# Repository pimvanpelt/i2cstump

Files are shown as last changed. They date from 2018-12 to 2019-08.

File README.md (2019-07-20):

# Digistump I2C dongle

## Version 4 - USB Dongle

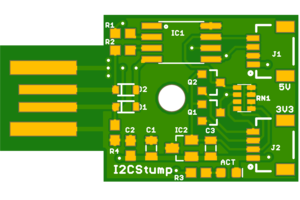
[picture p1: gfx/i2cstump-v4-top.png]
Top of I2CStump

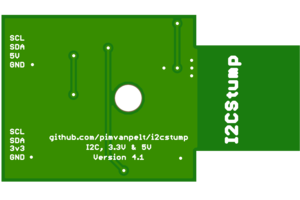
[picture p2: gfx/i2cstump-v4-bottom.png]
Bottom of I2CStump


## Version 5 - USB-C Connector

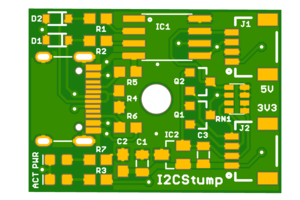
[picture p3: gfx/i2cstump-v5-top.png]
Top of I2CStump

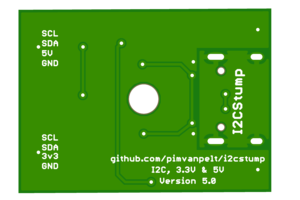
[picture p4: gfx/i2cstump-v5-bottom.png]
Bottom of I2CStump


## Hardware 

This device is an adaptation of [Digistump](http://digistump.com/products/1)'s
USB device, with two added [Qwiic](https://www.sparkfun.com/qwiic) connectors.
The first is used as a 5V I2C port, and the second has a level shifter to 3.3V
using [BSS138](https://www.onsemi.com/pub/Collateral/BSS138-D.PDF) FETs to
create a 3.3V I2C port. It's slightly bigger than the original, coming in 
at 34.0 x 18.7 mm (for the stump, which plugs directly into a USB port), or
25.9 x 18.8 mm (for the USB-C version)..

See my Oshpark projects: [v2](https://oshpark.com/shared_projects/iBBtdp7S),
[v3](https://oshpark.com/shared_projects/8I7qjXw7), 
[v4](https://oshpark.com/shared_projects/ChwKt4Mn),
[current-v5](https://oshpark.com/shared_projects/Jq9YXZ0q).

You can see a few pictures of the v3 board [here](https://photos.app.goo.gl/4XRo74y9Bt4kZoqR7).

### Bill of Materials

*   C1,C3: Tantalum 4.7 μF (0805)
*   C2: Ceramic 0.1 μF (0603)
*   D1,D2: 3.6V Zener (SOD-323)
*   D3: Blue (activity) LED (0603)
*   D4: Red (power) LED (0603)
*   IC1: ATTINY85 (SO08)
*   IC2:
    *   v2: AM1117 3.3V (SOT223)
    *   v3+: MCP1703 3.3V (SOT23)
*   J1,J2: QWIIC Connector (1X04 1MM RA)
*   Q1,Q2: BSS138 (SOT23-3)
*   R1,R2: 66 Ω (0603)
*   R3,R7: 680 Ω (0603)
*   R4: 2.2 kΩ (0603)
*   R5,R6: 5.1 kΩ (0603)
*   RN1: 10 kΩ (0805)
*   USB-C 16 pin connector

To build this board by hand, take a look at the [instructions](BUILDING.md).

## Firmware

The ATTiny85 is first flashed with [Micronucleus](https://github.com/micronucleus/micronucleus),
a bootloader which equips the microcontroller with a minimal USB interface. You can use the
`ICSP` touchpoint header at the bottom of the board to flash.

Firmware which runs under the micronucleus bootloader is [I2C-Tiny-USB](https://github.com/harbaum/I2C-Tiny-USB)
which is detected under Linux using the [i2c-tiny-usb](https://github.com/torvalds/linux/blob/master/drivers/i2c/busses/i2c-tiny-usb.c)
driver.

## Acknowledgements

Thanks go to:

*   Digistump LLC for sharing the original for this device under Creative Commons.
*   Tim Böscke, Jenna Fox, Shay Green et al for the Micronucleus bootloader.
*   Till Harbaum for an excellent ATTINY85 firmware for an I2C bridge.

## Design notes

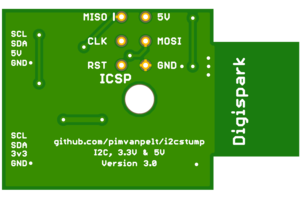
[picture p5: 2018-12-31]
gfx/i2cstump-v3-bottom.png

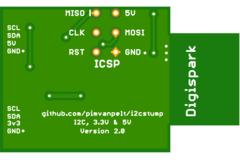
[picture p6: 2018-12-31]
gfx/i2cstump-v2-bottom.png

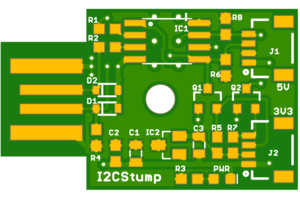
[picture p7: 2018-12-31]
gfx/i2cstump-v3-top.png

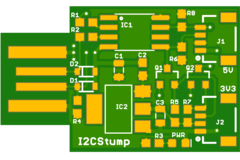
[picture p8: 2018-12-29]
gfx/i2cstump-v0.png

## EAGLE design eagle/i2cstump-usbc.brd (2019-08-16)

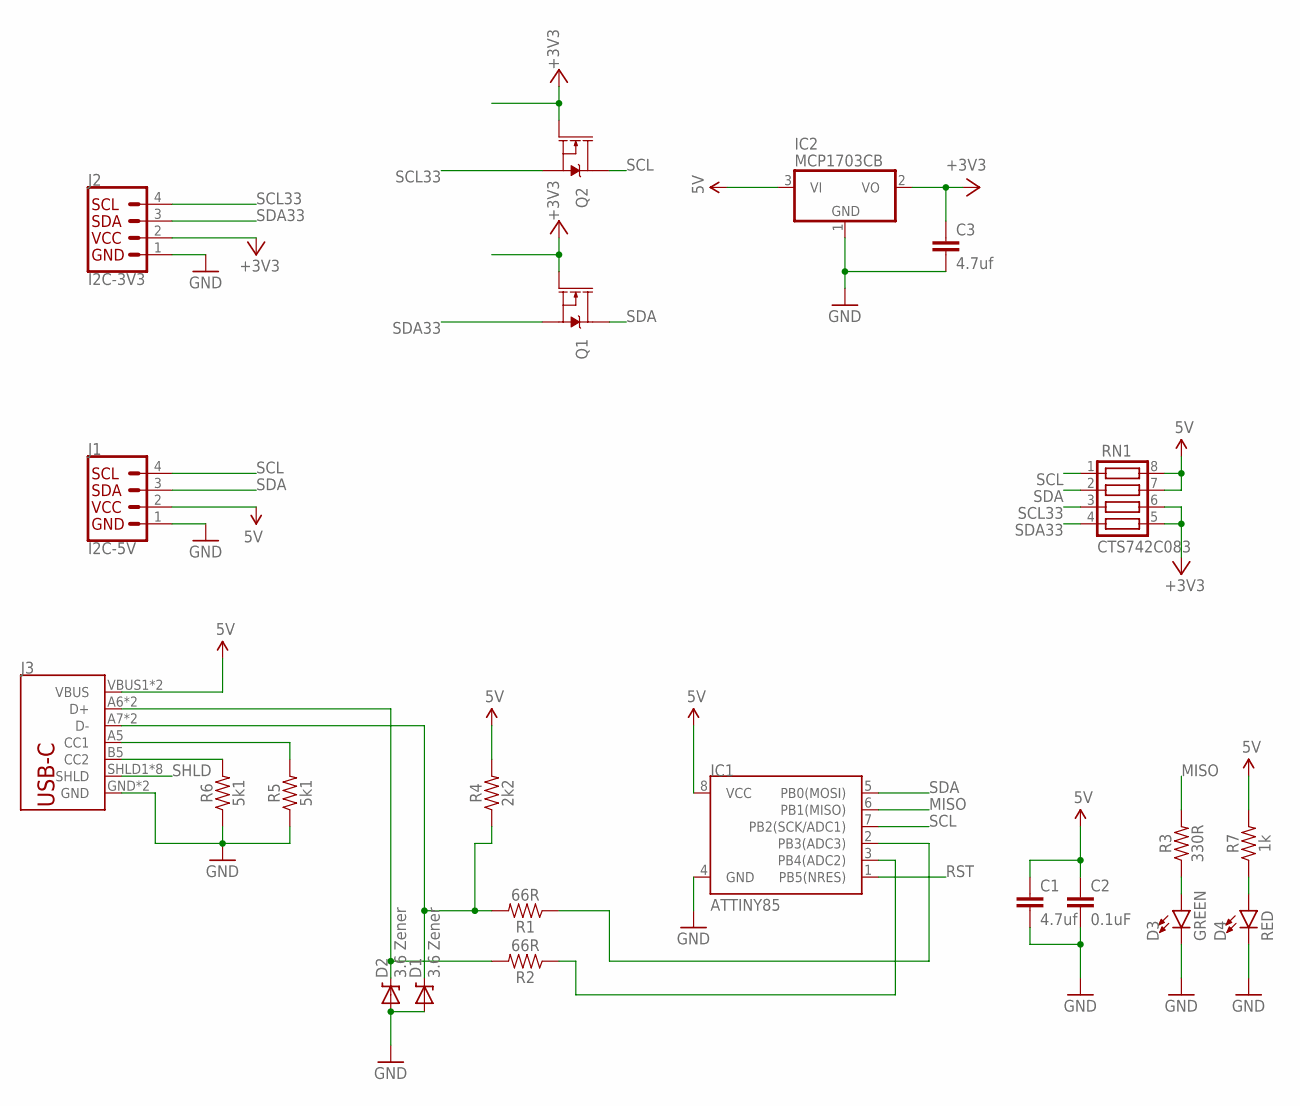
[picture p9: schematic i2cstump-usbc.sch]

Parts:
C1, C3: 4.7uf; 0805
C2: 0.1uF; 0603
D1, D2: 3.6 Zener; SOD-323
D3: GREEN; LED-0603
D4: RED; LED-0603
IC1: ATTINY85; SO08-EIAJ
IC2: MCP1703CB; SOT23
J1: I2C-5V; 1X04_1MM_RA
J2: I2C-3V3; 1X04_1MM_RA
J3: USB_C16PIN; USB-C-16P
Q1, Q2: 220mA/50V/3.5Ω; SOT23-3
R1, R2: 66R; 0603
R3: 330R; 0603
R4: 2k2; 0603
R5, R6: 5k1; 0603
R7: 1k; 0603
RN1: CTS742C083

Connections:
5V: C1.1, C2.1, IC1.8 (VCC), IC2.3 (VI), J1.2 (VCC), J3.VBUS1 (VBUS), J3.VBUS2 (VBUS), R4.2, R7.2, RN1.7, RN1.8
+3V3: C3.1, IC2.2 (VO), J2.2 (VCC), Q1.1 (G), Q2.1 (G), RN1.5, RN1.6
GND: C1.2, C2.2, C3.2, D1.2 (A), D2.2 (A), D3.C, D4.C, IC1.4 (GND), IC2.1 (GND), J1.1 (GND), J2.1 (GND), J3.GND, J3.GND2 (GND), R5.1, R6.1
MISO: IC1.6 (PB1(MISO)), R3.2
unnamed: IC1.2 (PB3(ADC3)), R1.1
unnamed: D3.A, R3.1
unnamed: D4.A, R7.1
unnamed: J3.A5 (CC1), R5.2
unnamed: J3.B5 (CC2), R6.2
unnamed: IC1.3 (PB4(ADC2)), R2.1
RST: IC1.1 (PB5(NRES))
SCL: IC1.7 (PB2(SCK/ADC1)), J1.4 (SCL), Q2.3 (D), RN1.1
SCL33: J2.4 (SCL), Q2.2 (S), RN1.3
SDA: IC1.5 (PB0(MOSI)), J1.3 (SDA), Q1.3 (D), RN1.2
SDA33: J2.3 (SDA), Q1.2 (S), RN1.4
SHLD: J3.SHLD1 (SHLD), J3.SHLD2 (SHLD), J3.SHLD3 (SHLD), J3.SHLD4 (SHLD), J3.SHLD5 (SHLD), J3.SHLD6 (SHLD), J3.SHLD7 (SHLD), J3.SHLD8 (SHLD)
USB_M: D1.1 (C), J3.A7 (D-), J3.B7 (D-), R1.2, R4.1
USB_P: D2.1 (C), J3.A6 (D+), J3.B6 (D+), R2.2

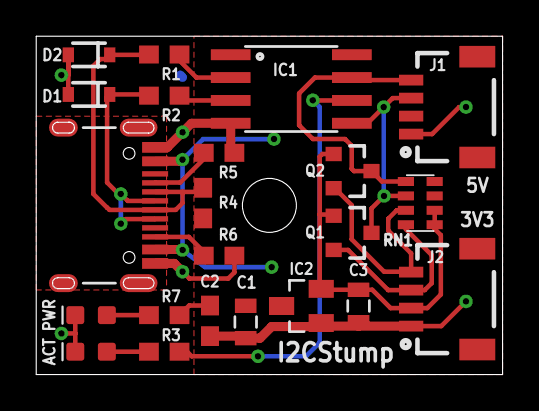
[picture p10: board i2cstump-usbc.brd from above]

Board: 2 copper layers, 25.9 x 18.8 mm, 22 parts (0 on the bottom side), 17 nets.

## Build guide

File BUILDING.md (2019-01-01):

# Building

The build of this device happens in a a few stages. First, the MCU is soldered
to the board. Then, `micronucleus` is flashed to it using the `ICSP` header.
Next, the USB components are soldered, exposing the MCU to your host machine
and allowing us to flash the application firmware `I2C Tiny USB`.

Then, the 5V I2C components are soldered. Finally, the 3.3V I2C components
are soldered (which is optional, and only needed if you intend to use the
3.3V I2C bus.

## The MCU

Solder `IC1` (the ATTiny85) onto the board.

### Flashing Micronucleus

Using `avrdude`, flash micronucleus bootloader onto the MCU. There are many
ways to drive `avrdude`, for example using an `usbasp` or `usbtiny` device,
or using an Arduino ISP with `arduino`, or using a Raspberry Pi with
`linuxgpio`.

See [this instructable](https://www.instructables.com/id/Refresh-Your-DigiSpark-clone-With-a-Smaller-Bootlo/)
for some background information.

Also, several eFuses have to be set. For information on fuses, take a look
[here](http://www.engbedded.com/fusecalc/).

Assuming some knowledge with `avrdude`, here's an example
commandline:

```
cd src/micronucleus/firmware
make t85_default
avrdude -c linuxgpio -p t85 -U flash:w:main.hex \
  -U lfuse:w:0xe1:m -U hfuse:w:0xdd:m -U efuse:w:0xfe:m
```

## USB Components

Solder `D1,D2` zener diodes. They will pull the data lines of the USB bus
to 3.6V (the USB specification wants 3.3V datalines, while our MCU is operating
at 5V). 

Solder `R1,R2`, which are current limiters to the MCU's input pins.

Solder `R4`, which pulls the `USB-` dataline to 5V, signalling to the host
that we are a low speed USB device.

### Flashing I2C Tiny USB

Connecting the device to a host computer will now show the Micronucleus USB
device. You may want to install the [udev rules](https://github.com/micronucleus/micronucleus/blob/master/commandline/49-micronucleus.rules)
so that you can run `micronucleus` as user.

```
sudo cp src/micronucleus/commandline/49-micronucleus.rules /etc/udev/rules.d/
sudo service udev restart

cd src/I2C-Tiny-USB/digispark
make hex
micronucleus --run --dump-progress --type intel-hex main.hex
```

Plug in your device at the prompt, and the application will be flashed. Shortly
after finishing, the device will be recognized as a `i2c-tiny-usb` and connected
to a Linux `i2c` bus. Running `i2cdetect -l` will show it.

## 5V I2C Components

Solder `J1` to the board. This is the 5V I2C bus Qwiic connector.
Solder `R6, R8` to the board. These are the I2C pullup resistors for the 5V bus.

You should now be able to communicate with 5V I2C devices!

## Optional Components

### 3.3V I2C Components

Solder `J2` to the board. This is the 3.3V I2C bus Qwiic connector.
Solder `R5, R7` to the board. These are the I2C pullup resistors for the 3.3V
bus.
Solder `Q1, Q2` to the board. These are level shifters between the 5V logic on
the board and the 3.3V I2C bus lines.
Solder `IC2` to the board. This is a 3.3V voltage LDO that powers the 3.3V I2C
bus.
Solder `C1, C2, C3` to the board. These are capacitors for the input and output
voltage lines of the LDO.

You should now be able to communicate with 3.3V I2C devices!

### Power LED

If you'd like to see if the device is powered, solder `D3` and `R3` to the
board.

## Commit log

2018-12-29 V1.0 -- ordered @oshpark
    [i2cstump.brd, i2cstump.sch]
2018-12-29 Remove text from Digispark -- will attribute in README.md
    [i2cstump.sch]
2018-12-29 Update with BOM
2018-12-29 Clean up schematic -- split out the levelshifter from the 5V pullups
    [i2cstump.brd, i2cstump.sch]
2018-12-29 Cleanup BRD -- remove stubs, remove redundant 5V traces (they are on the top plane), widen 5V and GND traces to 0.02
    [i2cstump.brd]
2018-12-29 Add back groundplane to image
2018-12-29 Add some more GND via's - name USB_M and USB_P; Move AM1117 a bit so that 5V has more copper on ingress
    [i2cstump.brd, i2cstump.sch]
2018-12-29 Move AM1117 a bit to the left again, as it was really close to C3
    [i2cstump.brd]
2018-12-29 Add C3 to BOM
2018-12-31 Version 2.0
    Now with ICSP touchpoints at the bottom so I can flash the AVR.
    Also placed tantalum cap C3 (4.uF) on the output of the AM1117.
    [i2cstump.brd, i2cstump.sch]
2018-12-31 Version 3.0 -- with 3mm screwhole in the center. Aligned J1/J2 to be 0.76mm from the edges. Replaced bulky AM1117 (SOT223) with a MCP1700 (SOT23)
    [i2cstump.brd, i2cstump.sch]
2018-12-31 Change R3 to 390R, 2.2V green LED, not too bright
    [i2cstump.brd, i2cstump.sch]
2019-01-01 Move D1,D2,C3 silk around; center other silk
    [i2cstump.brd]
2019-01-01 Add fusecalc link
2019-07-01 Move R4 to align with C1/C2
    [i2cstump.brd]
2019-07-08 Version 4.0
    Changes:
    - swap out PWR led for ACT led on MISO pin (the USB Tiny I2C firmware
    blinks MISO on I2C activity.
    - swap out 10KOhm pullup resistors for an 0805 resistor network RN1.
    [i2cstump.brd, i2cstump.sch]
2019-07-08 Update v4 to be RN1 for I2C pullups
2019-07-20 Version 5 of the board - USB-C!
    [i2cstump-usbc.brd, i2cstump-usbc.sch]
2019-07-20 Add a few mm of length to the USB stump
    [i2cstump.brd]
2019-07-20 Reference proper dimensions of the v4 and v5 board
2019-07-20 Correct geometry of the v5 board (it was off-by-5mils)
    [i2cstump-usbc.brd]
2019-07-20 Center the USB-C connector
    [i2cstump-usbc.brd]
2019-07-20 Move hole to center of board
    [i2cstump-usbc.brd]
2019-08-15 Correct value of R7 (390R)
    [i2cstump-usbc.brd, i2cstump-usbc.sch]
2019-08-16 Change red PWR led to be 1k resistor so it's not as bright. Conversely, lower green ACT led to 330R so it's a bit brighter
    [i2cstump-usbc.brd, i2cstump-usbc.sch]

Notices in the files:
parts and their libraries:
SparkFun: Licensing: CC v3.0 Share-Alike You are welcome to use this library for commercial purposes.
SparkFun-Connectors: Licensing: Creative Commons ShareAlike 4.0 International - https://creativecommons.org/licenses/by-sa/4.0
